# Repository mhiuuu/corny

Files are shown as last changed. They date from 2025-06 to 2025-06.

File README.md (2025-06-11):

# Corny Split Keyboard

My first custom split keyboard that takes inspiration from the [Corne keyboard](https://www.boardsource.xyz/products/Corne).

---

## Motivation

I’m pretty much a geek who always finds ways to create things tailored specifically for myself. I've been using Arch Linux (BTW), Hyprland (BTW), and Neovim (BTW) for over a year now, and most of my workflow depends heavily on the keyboard.

Over time, I’ve tried 60%, 75%, and 100% mechanical keyboards. They’re all nice, but I struggled to find space on my desk for schoolwork, and placing the keyboard on my laptop caused the battery to heat up. Then one day, I stumbled upon [this video](https://youtu.be/7UXsD7nSfDY?si=9aiY0pJiT80jEVwv), which sparked the idea—and here it is: my first-ever custom-built split keyboard. All the design work was done in less than 5 days.

---

## Build

This keyboard was created using [Ergogen](https://github.com/ergogen/ergogen), with extra helpful guidance from the [Flatfootfox tutorial](https://flatfootfox.com) and HunterCook—a genius and my friend on Discord.

The design is entirely customized for my hand movements and habits. It may not suit your typing style (or even mine, as this is my first attempt). All routing was done manually and can be found in the `ergogen/results/pcbs/` directory, not in `ergogen/output/pcbs`, which contains files auto-generated by Ergogen.

---

### 1. Layout

The layout was fully created inside [Ergogen](https://ergogen.ceoloide.com).

Here’s my initial design of _Corny_, drawn in Excalidraw:
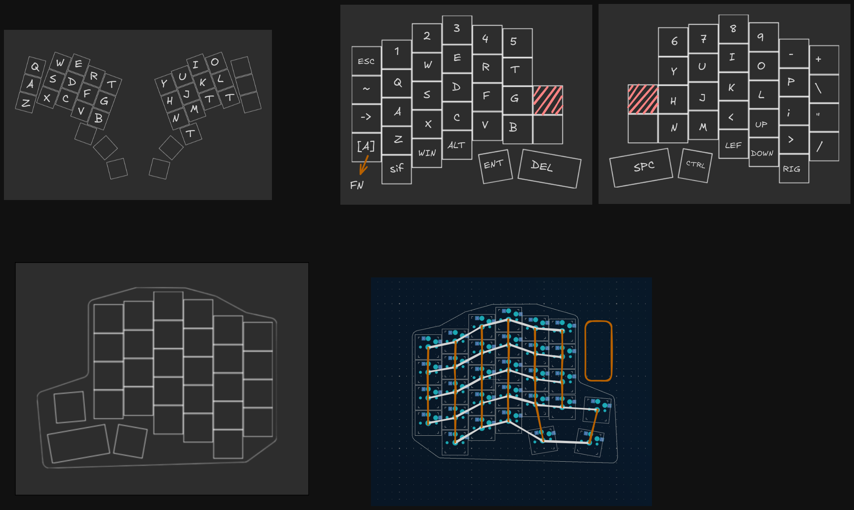
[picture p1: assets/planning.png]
Excalidraw


It was draw in the first day with some adjustments. However, while working on the board I realized that I forgot the `{}` and the `FN` key so I have to make some changes

1. Adding one more thumb key to each side (It was 2 but I have enough place for all the key I need now)
2. Changing the `CAPSLOCK` to `FN` cuz who even use it now?

---

### 2. Components

For switches, I decided to use `MX switches` instead of `Choc switches` like most others, because MX switches are much easier to find in Vietnam. In fact, I couldn’t find any retailers selling Choc switches on the major e-commerce platforms here. My switch of choice is the [Akko Rosewood](https://en.akkogear.com/product/akko-rosewood-switch/).

> Choc switch (low profile): 17×18mm

> MX switch (The type of switch on normal mechanical keyboard): 19×19mm

For the MCU, I used the [nice!nano v2](https://typeractive.xyz/products/nice-nano?variant=42225114546407) for wireless functionality despite of the fact that you can see, yep obviously the MCU in the PCBS are `nice!nano_v1` but I could only find the version 2. However, you can use almost any available MCU, such as the [Pro Micro](https://hshop.vn/arduino-pro-micro) or even a [Raspberry Pi Zero](https://www.raspberrypi.com/products/raspberry-pi-zero/).

---

### 3. PCBs

The PCBs were auto-generated by [Ergogen](https://ergogen.ceoloide.com) in `.kicad_pcb` format, which you can open in [KiCad](https://www.kicad.org/). Be sure to connect all routes manually, and aim for an `unrouted` count of zero—otherwise, you'll have unconnected components (oops!).

I had a hard time with the PCBs when I was connecting everything and remembered that _damn this should not be here_ so make sure connecting all the important components first (hardest part) before working with the keys

The finished PCBs are located in `./PCBs/` not in `./ergogen/output/pcbs/`, they are auto generated by ergogen

Here are the final PCB designs:

| Left Plate | Right Plate |
| --- | --- |
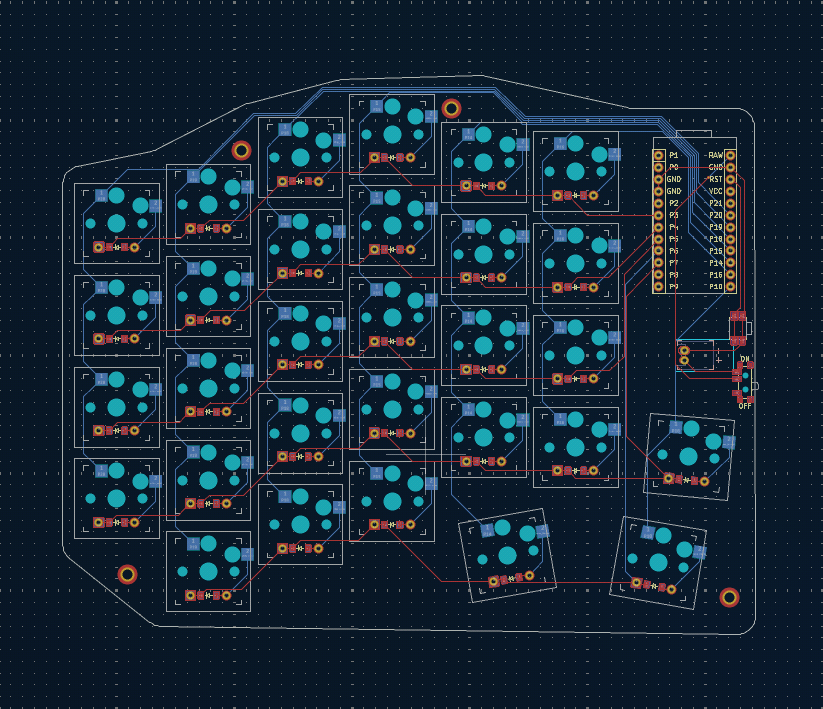
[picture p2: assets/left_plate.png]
let_plate
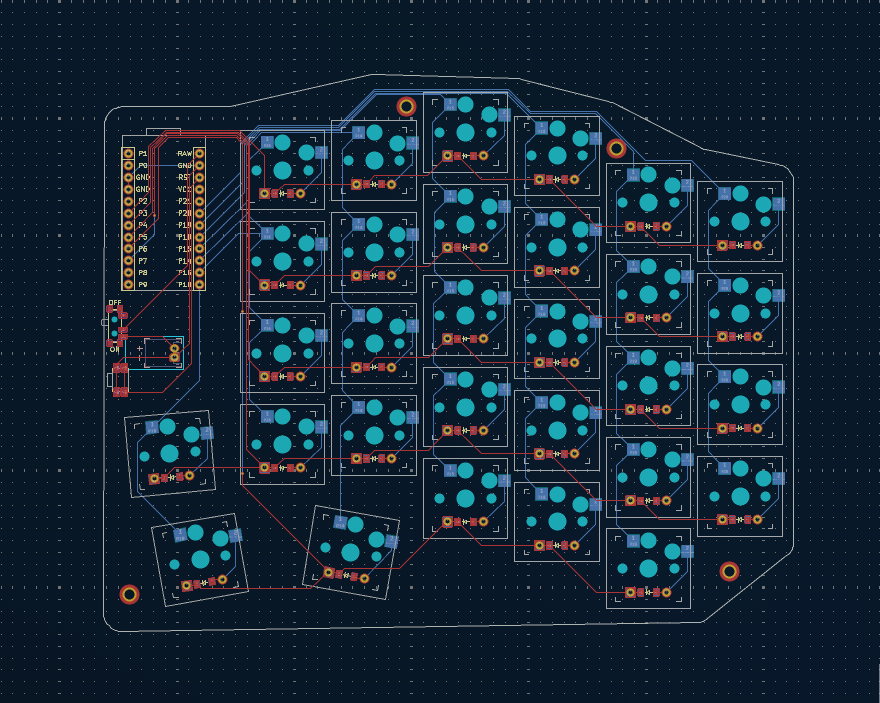
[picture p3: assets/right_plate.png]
|  |  |

---

### 4. Cases

## Version 1:

Design the case inside ergogen is possible. However, it was a pain in the ass so I made a dirty (or genius?) move by making half of the case in ergogen, the eport it in `jscad` convert to `stl` using the `@jscad/cli@1` package and then put it inside [OnShape](https://cad.onshape.com) then delete the wrong part

Here is the image of the final `stl` file

| Left case | Right case |
| --- | --- |
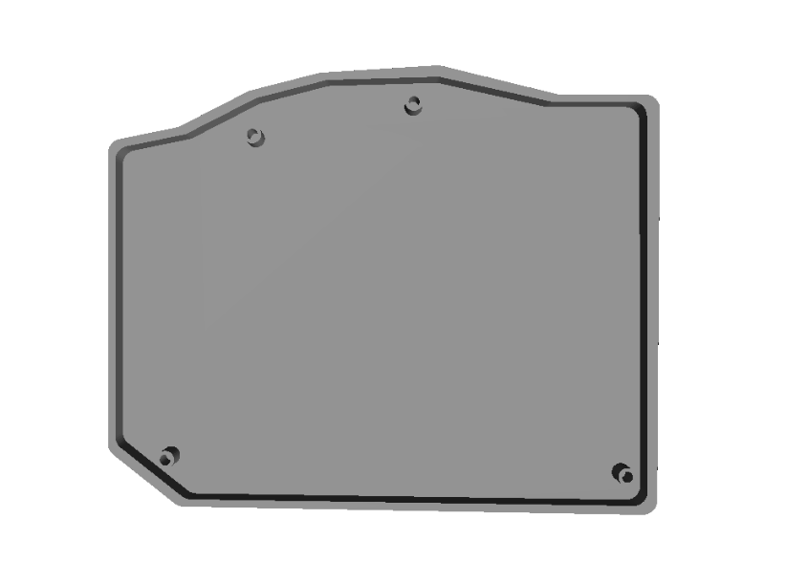
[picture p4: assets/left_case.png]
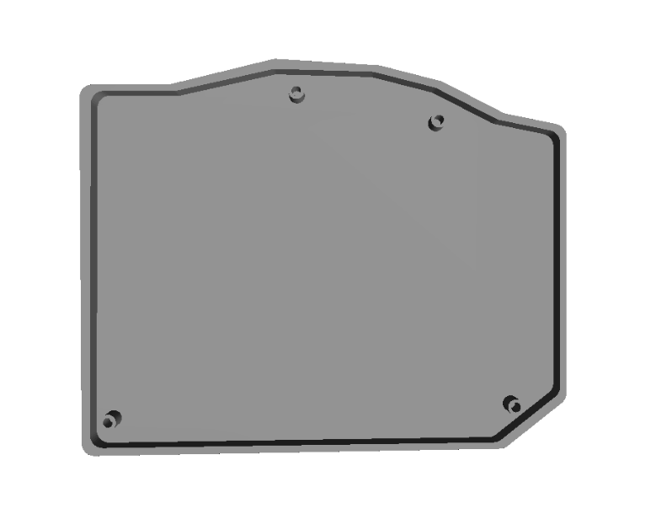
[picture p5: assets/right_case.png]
|  |  |

P/s: Im praying that the mounting hole will fit

## Version 2:

The case was denied because it was just a basic outline which you can literally create anywhere using a case genereator. So I decided to sit back and start working with [OnShaped](https://cad.onshape.com) to design a new case.

First, I imported the `.dxf` files from the `./ergogen/output/outline` and lay it on to the sketch so that I can have a brief view of what the outlines are. (Disclaimer: the outline is 10 times the actual size so after all you have to scale it down) Then I extrude the parts I need to create a simple case as the `version_1`.

Then I have to create the nut for M2 screws but I had had a bad time with creating custom nut and screw so I decided to use the public version of a M2 nut and extrude it so that it has a little margin I need to stand the PCBs.

Next step is the worst step you can imagine, making the top plate!!! I had to redo the first step of making the case (creating a plate without the walls) the align it so that the keys hole and the plate aligned perfectly. Then I had to extrude each key individually!!!!! That is over 30 keys and yes it took a whooping amount of timeto do it. Also remember to cut the hole for the MCU to (you don't want to cut it manually when you got the 3D printed case tho)

Penultimate is the piercing hole for the velcro strap. This create 2 holes so that you can use the velcro strap to strap the keyboard around your leg when you are on a plane/train or just simply don't have the space for you keyboard.
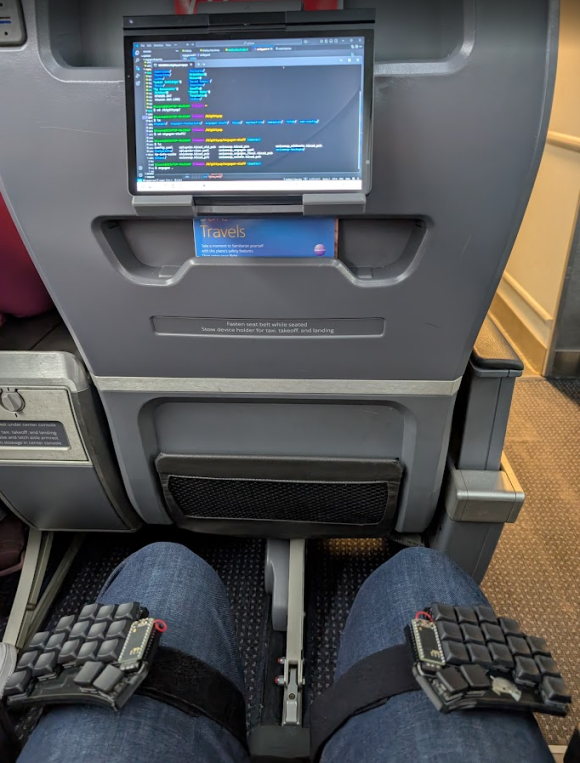
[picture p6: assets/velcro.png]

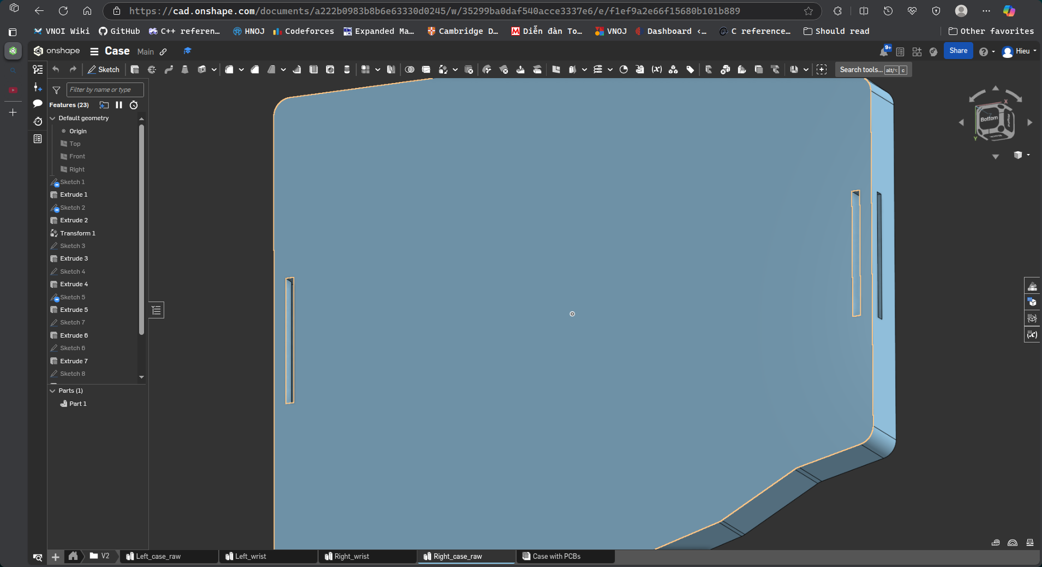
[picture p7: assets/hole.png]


Final parts are the detachable wrist rest using magnet. I use two 6mmx1.5mm magnet mounted to the case so that you can attach and remove the wrist rest with ease.
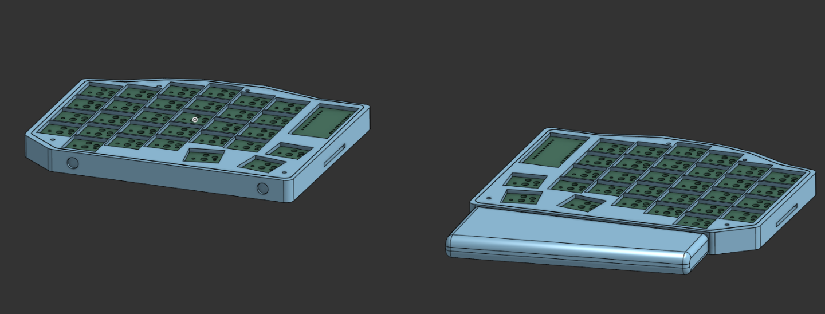
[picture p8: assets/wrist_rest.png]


---

### 5. The software

I haven't had fund to get the parts yet but there is a tool called [zmk](/zmk-corny-config/) - I will keep the repo private for now since I am just doing it blindly without the physical parts

---

### 6. BOM

AYou can check the BOM in [here](/Corny_BOM.csv). As you can see, the prices look a bit messy—that's the best I could do when converting between VND and USD (inflation is killing me). Only Shopee Vietnam, a Vietnamese e-commerce platform, lists exact prices in VND, which I then converted to USD. All the other retailers charge in USD. Even more frustrating, Typeractive actually charges more in VND than in USD!

#### Electronics

| No. | Parts | Unit cost (USD) | Unit cost (VND) | Quantity | Retailer | Shipping + Tax (USD) | Shipping + Tax (VND) | Total cost (USD) | Total cost (VND) | Source | Note |
| --- | --- | --- | --- | --- | --- | --- | --- | --- | --- | --- | ---- |
| 1 | Nice!nano MCU | 25.41 | 662,000 | 2 | Typeractive | Free | Free | 50.82 | 1324000 | https://typeractive.xyz/products/nice-nano?variant=42225114546407 | |
| 2 | Power Switch | 1.54 | 40,000 | 1 | Typeractive | Free | Free | 1.54 | 40000 | https://typeractive.xyz/products/power-switch?variant=45597854171367 | |
| 3 | Diodes | 0.77 | 20,000 | 6 | Typeractive | Free | Free | 5.62 | 120000 | https://typeractive.xyz/products/smd-diodes?variant=45597514858727 | |
| 4 | Reset button | 1.54 | 40,000 | 1 | Typeractive | Free | Free | 1.54 | 40000 | https://typeractive.xyz/products/reset-button?variant=45597784932583 | |
| 5 | Battery jack | 1.04 | 27,000 | 1 | Typeractive | Free | Free | 1.04 | 27000 | https://typeractive.xyz/products/battery-jack?_pos=2&_psq=bat&_ss=e&_v=1.0 | |
| 6 | Machine Sockets and Pins | 6.61 | 172,000 | 2 | Typeractive | Free | Free | 13.22 | 344000 | https://typeractive.xyz/products/machine-sockets-and-pins?variant=45741664469223 | |
| 7 | Kailh Hotswap Sockets | 1.54 | 40,000 | 6 | Typeractive | Free | Free | 9.24 | 240000 | https://typeractive.xyz/products/hotswap-sockets?_pos=1&_psq=hot&_ss=e&_v=1.0 | |
| 8 | PCBs | 10.7 | 278,960 | 2 | JLCPCB | 12.47 | 324,470 | 33.87 | 882390 | https://jlcpcb.com | |
| 9 | Battery | 1.53 | 39,820 | 2 | Shopee VN | 0.39 | 10,000 | 3.45 | 89640 | https://shopee.vn/Ehbqna-103450-Pin-s%E1%BA%A1c-lithium-polymer-lipo-3.7V-2000MAH-m%E1%BB%9Bi-i.240549284.26978776277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 | |

**Electronics Total**: **119.34 USD** / **3,107,030 VND**

#### Hardware

| No. | Parts | Unit cost (USD) | Unit cost (VND) | Quantity | Retailer  | Shipping + Tax (USD) | Shipping + Tax (VND) | Total cost (USD) | Total cost (VND) | Source | Note  |
| --- | --- | --- | --- | --- | --- | --- | --- | --- | --- | --- | ----- |
| 1 | Akko Rosewood | 0.29 | 7,499 | 60 | Shopee VN | 0.64 | 16,500 | 18.04 | 466440 | https://shopee.vn/Switch-Akko-Cream-V3-Pro-Yellow-Blue-Piano-Silent-Fairy-Linear-Penguin-Tactile-Switch-Akko-Cream-Yellow-Blue-DoDo-Gear-i.665488736.23277505182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 | |
| 2 | Keycaps | 0.38 | 9,900 | 58 | Shopee VN | 0.71 | 18,300 | 22.75 | 592500 | https://shopee.vn/-Cherry-Keycap-Blank-1u-Trong-Su%E1%BB%91t-N%C3%BAt-Keycap-L%E1%BA%BB-Trong-Su%E1%BB%91t-Cho-B%C3%A0n-Ph%C3%ADm-C%C6%A1-Switch-Tester-YMDK-Cherry-P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 | |
| 3 | Solder | 2.49 | 65,000 | 1 | Shopee VN | 0.64 | 16,500 | 3.13 | 81500 | https://shopee.vn/Thi%E1%BA%BFc-H%C3%A0n-63-37-SN63-Flux-1.8-Cu%E1%BB%99n-50G-i.27117857.29208587865 | |
| 4 | Soldering station | N/A | N/A | N/A | Owned | - | - | - | - | | Owned |
| 5 | 3D printed cases  | 13.78 | 358,556 | 1 | JLCPCB | Free | Free | 13.78 | 358,556 | https://jlcpcb.com | |
| 6 | Tenting feet | 2.45 | 63,800 | 2 | Shopee VN | 0.58 | 15,000 | 4.9 | 142600 | https://shopee.vn/Mini-Di-%C4%90%E1%BB%99ng-H%E1%BB%A3p-Kim-K%E1%BA%BDm-Laptop-%C4%90%E1%BB%A9ng-B%C3%A0n-Ph%C3%ADm-M%C3%A1y-T%C3%ADnh-Ch%C3%A2n-Gi%C3%A1-%C4%90%E1%B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 | |

**Hardware Total**: **62.6 USD** / **1,641,596 VND**

---

### 💰 TOTAL COST

-   **Electronics**: 3,107,030 VND / 119.34 USD
-   **Hardware**: 1,641,596 VND / 62.6 USD
-   **Grand Total**: **4,748,626 VND / 181.94 USD**

_Disclaimer: When you try to converting VND to USD you can see that they are about ~1 dollar away from each other. It is because you can not accurately convert the price down to every cent._

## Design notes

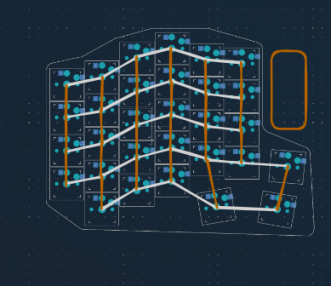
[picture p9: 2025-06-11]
assets/matrix_draft.png

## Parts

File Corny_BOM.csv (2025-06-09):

Electronics
No. | Parts | Unit cost (USD) | Unit cost (VND) | Quantity | Retailer | Shipping + Tax (USD) | Shipping + Tax (VND) | Total cost (USD) | Total cost (VND) | Source | Note
1 | Nice!nano MCU | 25.41 | 662,000 | 2 | Typeractive | Free | Free | 50.82 | 1324000 | https://typeractive.xyz/products/nice-nano?variant=42225114546407
2 | Power Switch | 1.54 | 40,000 | 1 | Typeractive | Free | Free | 1.54 | 40000 | https://typeractive.xyz/products/power-switch?variant=45597854171367
3 | Diodes | 0.77 | 20,000 | 6 | Typeractive | Free | Free | 4.62 | 120000 | https://typeractive.xyz/products/smd-diodes?variant=45597514858727
4 | Reset button | 1.54 | 40,000 | 1 | Typeractive | Free | Free | 1.54 | 40000 | https://typeractive.xyz/products/reset-button?variant=45597784932583
5 | Battery jack | 1.04 | 27,000 | 1 | Typeractive | Free | Free | 1.04 | 27000 | https://typeractive.xyz/products/battery-jack?_pos=2&_psq=bat&_ss=e&_v=1.0
6 | Machine Sockets and Pins | 6.61 | 172,000 | 2 | Typeractive | Free | Free | 13.22 | 344000 | https://typeractive.xyz/products/machine-sockets-and-pins?variant=45741664469223
7 | Kailh Hotswap Sockets (MX) | 1.54 | 40,000 | 6 | Typeractive | Free | Free | 9.24 | 240000 | https://typeractive.xyz/products/hotswap-sockets?_pos=1&_psq=hot&_ss=e&_v=1.0
8 | PCBs | 10.7 | 278,960 | 2 | JLCPCB | 12.47 | 324,470 | 33.87 | 882,390 | https://jlcpcb.com
9 | Battery | 1.53 | 39,820 | 2 | Shopee Vietnam | 0.39 | 10,000 | 3.45 | 89,640 | https://shopee.vn/Ehbqna-103450-Pin-s%E1%BA%A1c-lithium-polymer-lipo-3.7V-2000MAH-m%E1%BB%9Bi-i.240549284.26978776277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
TOTAL COST |  |  |  |  |  |  |  | 119.34 | 3107030
Hardware
No. | Parts | Unit cost | Unit cost (VND) | Quantity | Retailer | Shipping + Tax (USD) | Shipping + Tax (VND) | Total cost (USD) | Total cost (VND) | Source | Note
1 | Akko Rosewood | 0.29 | 7,499 | 60 | Shopee Vietnam | 0.64 | 16,500 | 18.04 | 466,440 | https://shopee.vn/Switch-Akko-Cream-V3-Pro-Yellow-Blue-Piano-Silent-Fairy-Linear-Penguin-Tactile-Switch-Akko-Cream-Yellow-Blue-DoDo-Gear-i.665488736.232775051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
2 | Keycaps | 0.38 | 9,900 | 58 | Shopee Vietnam | 0.71 | 18,300 | 22.75 | 592,500 | https://shopee.vn/-Cherry-Keycap-Blank-1u-Trong-Su%E1%BB%91t-N%C3%BAt-Keycap-L%E1%BA%BB-Trong-Su%E1%BB%91t-Cho-B%C3%A0n-Ph%C3%ADm-C%C6%A1-Switch-Tester-YMDK-C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
3 | Solder | 2.49 | 65,000 | 1 | Shopee Vietnam | 0.64 | 16,500 | 3.13 | 81,500 | https://shopee.vn/Thi%E1%BA%BFc-H%C3%A0n-63-37-SN63-Flux-1.8-Cu%E1%BB%99n-50G-i.27117857.29208587865
4 | Soldering station | N/A |  |  |  |  |  |  |  |  | Owned
5 | 3D Printed case | 13.78 | 358,556 | 1 | JLCPCB | Free | Free | 13.78 | 358,556 | https://jlcpcb.com | Shipping fee can be included with the PCBs
6 | Tenting feet | 2.45 | 63,800 | 2 | Shopee Vietnam | 0.58 | 15,000 | 4.9 | 142,600 | https://shopee.vn/Mini-Di-%C4%90%E1%BB%99ng-H%E1%BB%A3p-Kim-K%E1%BA%BDm-Laptop-%C4%90%E1%BB%A9ng-B%C3%A0n-Ph%C3%ADm-M%C3%A1y-T%C3%ADnh-Ch%C3%A2n-Gi%C3%A1-%C4%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
TOTAL COST |  |  |  |  |  |  |  | 62.6 | 1,641,596
TOTAL COST
 |  | VND | USD
1 | Electronics | 3,107,030 | 119.34
2 | Hardware | 1,641,596 | 62.6
 | TOTAL | 4,748,626 | 181.94

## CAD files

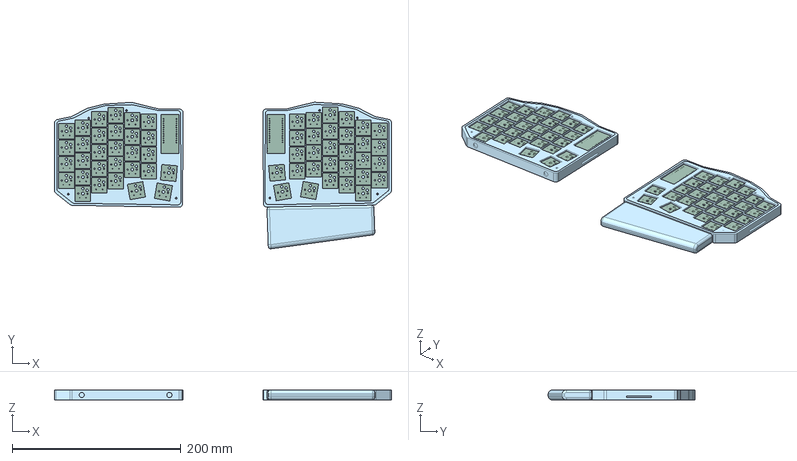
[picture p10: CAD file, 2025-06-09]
3D/V2/Case with PCBs.step
399.6 x 173.9 x 12.0 mm
M2 hex nut x 8
left_finished_PCB
right_finished_PCB

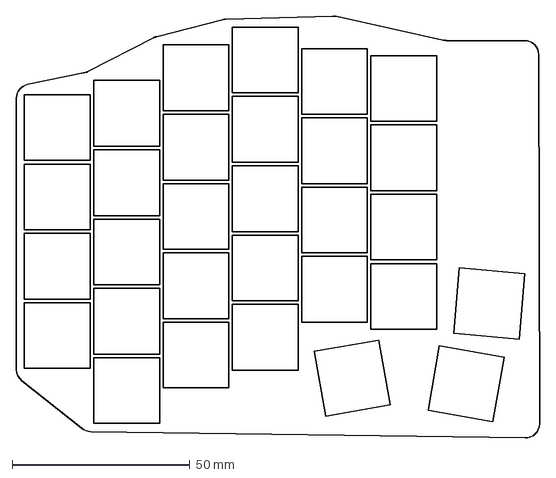
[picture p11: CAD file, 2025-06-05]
ergogen/output/outlines/combo.dxf
147.2 x 118.7 mm

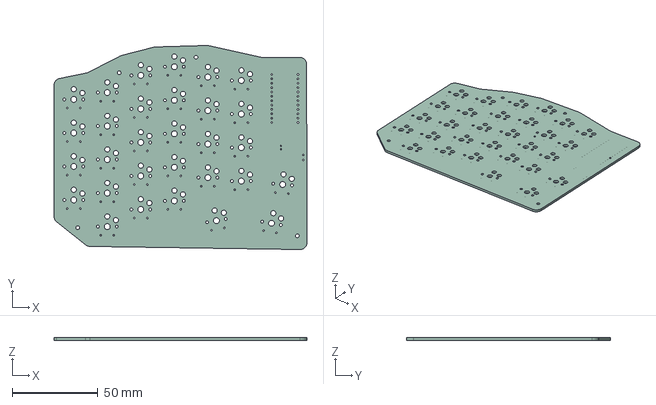
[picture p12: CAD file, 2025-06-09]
PCBs/left_finished.step
147.2 x 118.7 x 1.51 mm

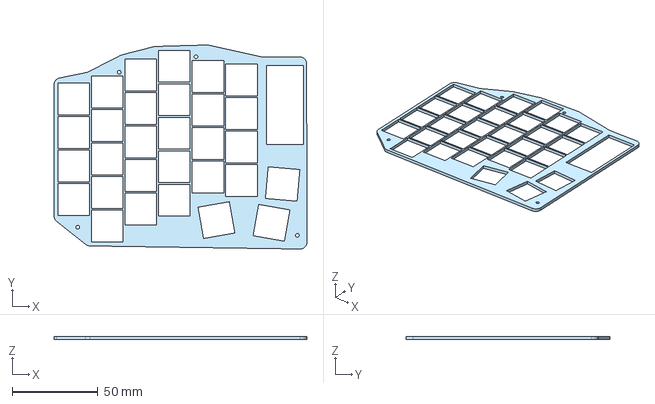
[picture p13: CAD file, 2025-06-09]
3D/V2/Top plate.step
147.2 x 118.7 x 2.00 mm

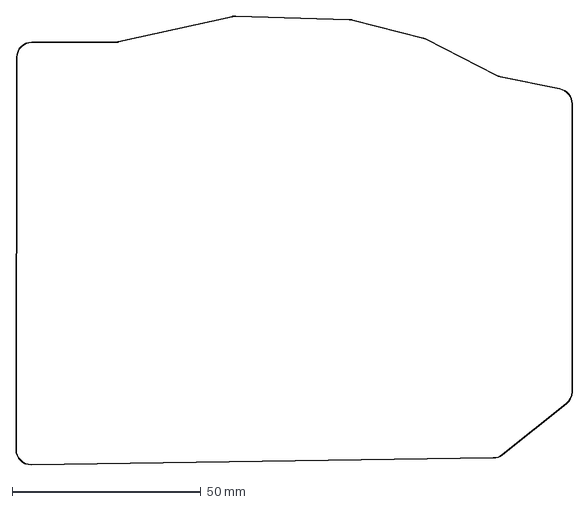
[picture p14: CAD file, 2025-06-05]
ergogen/output/outlines/board_right.dxf
147.2 x 118.7 mm

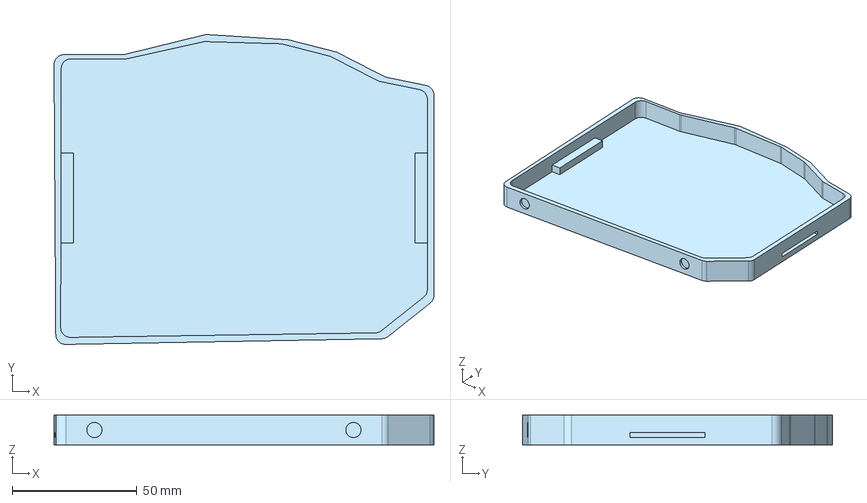
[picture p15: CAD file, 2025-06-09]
3D/V2/Right_case_raw.step
152.5 x 124.4 x 12.0 mm

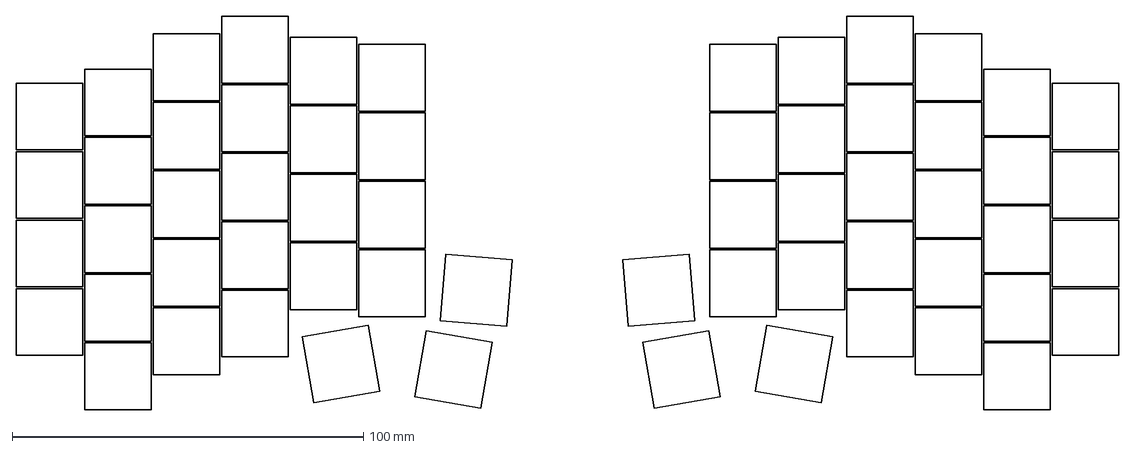
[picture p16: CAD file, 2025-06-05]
ergogen/output/outlines/raw.dxf
314.0 x 112.0 mm

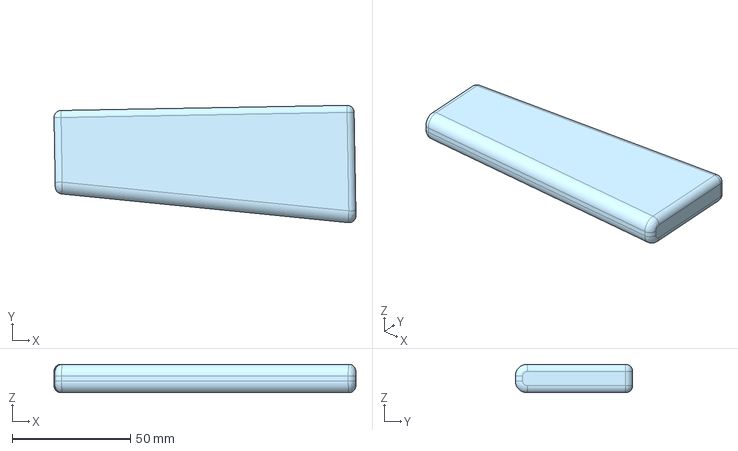
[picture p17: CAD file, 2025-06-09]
3D/V2/Right_wrist.step
127.7 x 49.6 x 12.0 mm

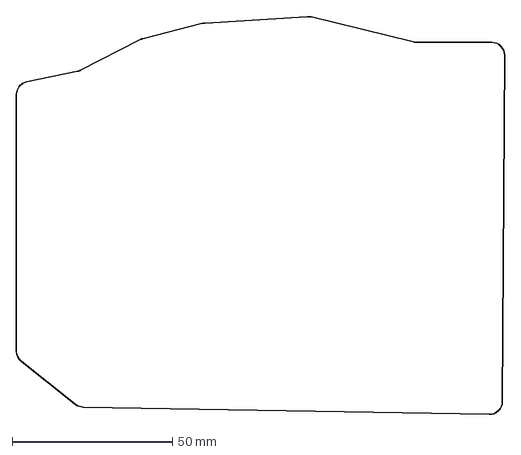
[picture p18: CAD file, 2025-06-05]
ergogen/output/outlines/xl_board_left.dxf
152.5 x 124.4 mm

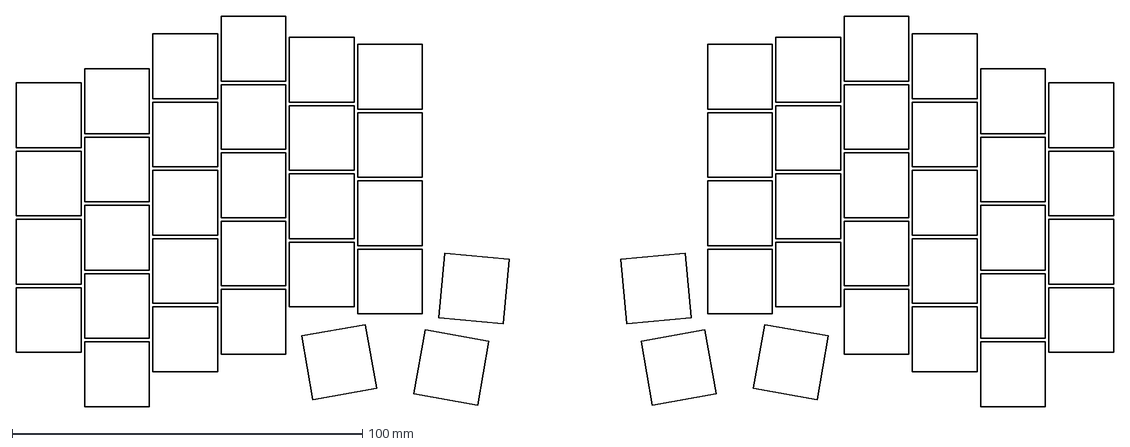
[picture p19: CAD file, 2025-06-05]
ergogen/output/outlines/keys.dxf
313.5 x 111.5 mm

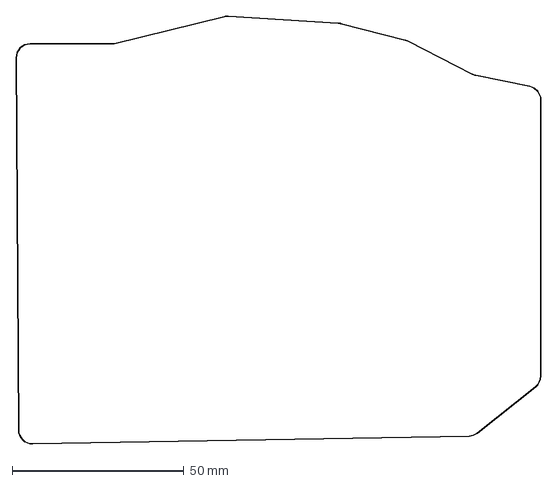
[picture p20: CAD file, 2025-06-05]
ergogen/output/outlines/xl_board_right.dxf
152.5 x 124.4 mm

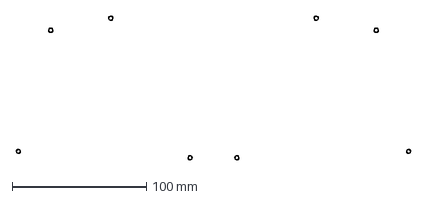
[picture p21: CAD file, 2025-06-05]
ergogen/output/outlines/mounting.dxf
293.4 x 106.9 mm

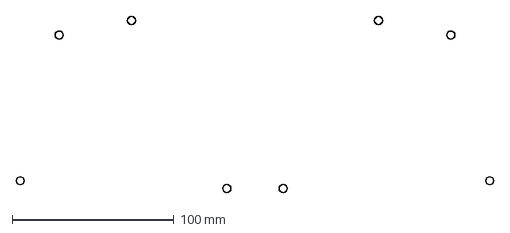
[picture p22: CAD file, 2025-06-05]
ergogen/output/outlines/standoff.dxf
295.4 x 108.9 mm

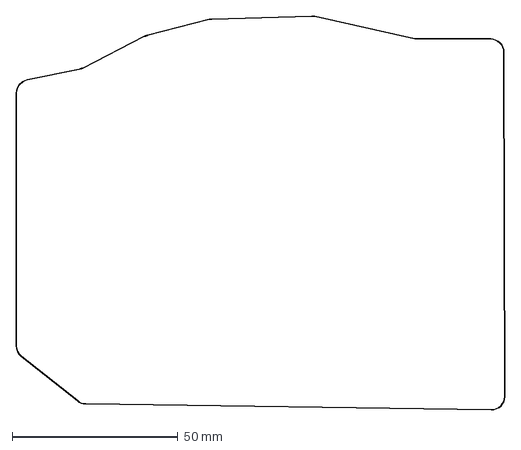
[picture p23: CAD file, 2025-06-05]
ergogen/output/outlines/board_left.dxf
147.2 x 118.7 mm

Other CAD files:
PCBs/right_finished.step
3D/V2/Left_wrist.step
3D/V2/Left_case_raw.step
3D/V1/left_case.step
3D/V1/left_case.stl
3D/V1/right_case.step
3D/V1/right_case.stl

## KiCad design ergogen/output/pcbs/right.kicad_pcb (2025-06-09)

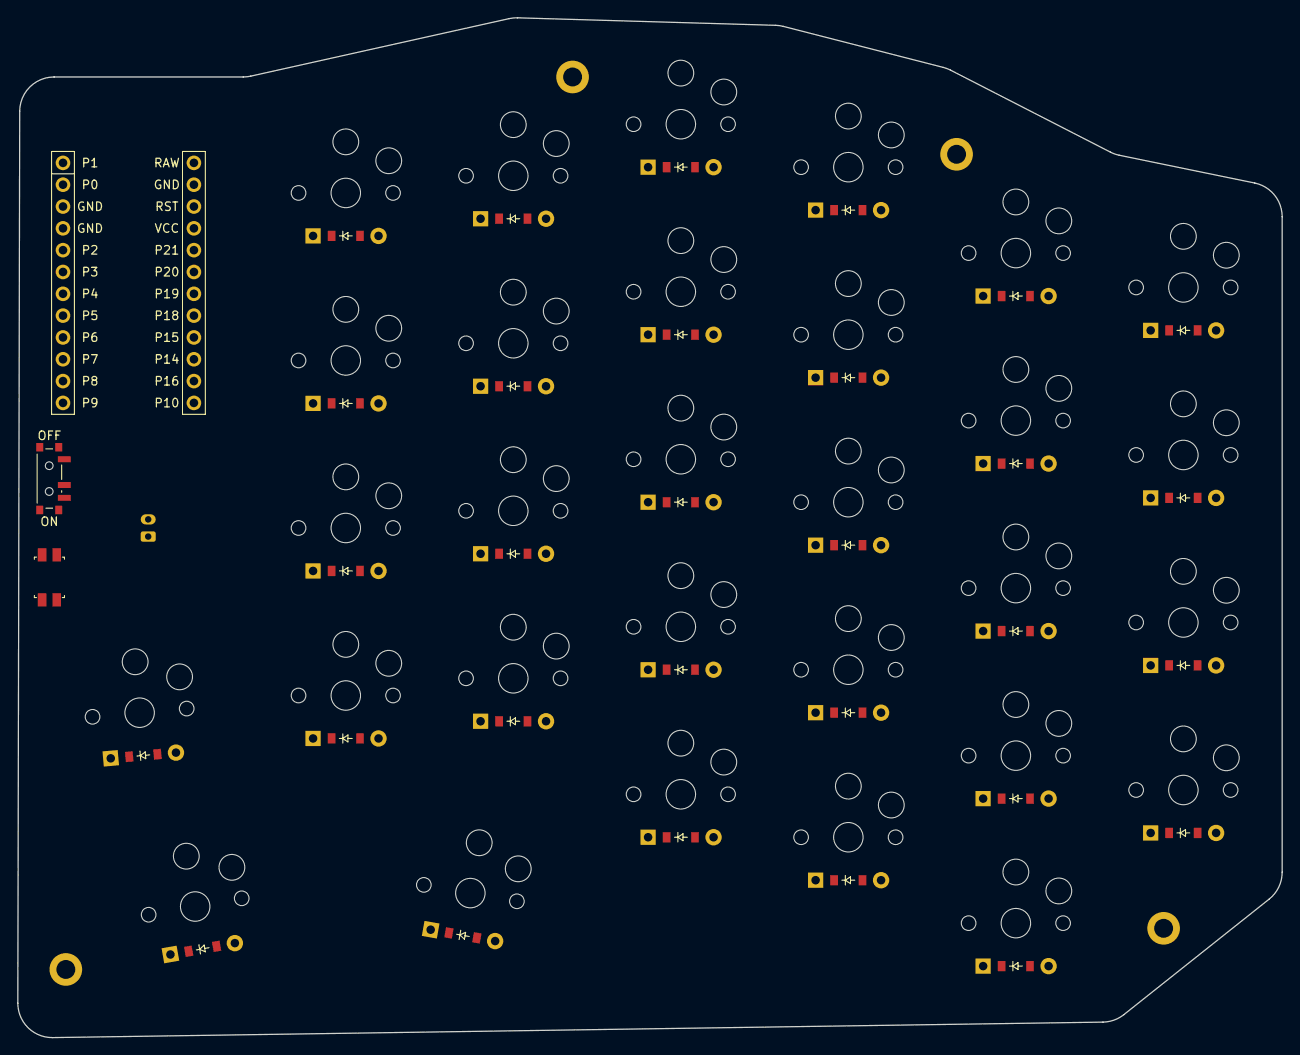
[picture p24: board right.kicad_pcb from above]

Board: 2 copper layers, 147.2 x 118.7 mm, 68 parts (1 on the bottom side), 46 nets, no tracks yet.

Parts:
D1, D2, D3, D4, D5, D6, D7, D8, D9, D10, D11, D12, D13, D14, D15, D16, D17, D18, D19, D20, D21, D22, D23, D24, D25, D26, D27, D28, D29, D30: ComboDiode
H1, H2, H3, H4: mounting_hole_plated
JST1: battery_connector_jst_ph_2
MCU1: mcu_nice_nano
PWR1: power_switch_smd_side
RST1: reset_switch_smd_side
S1, S2, S3, S4, S5, S6, S7, S8, S9, S10, S11, S12, S13, S14, S15, S16, S17, S18, S19, S20, S21, S22, S23, S24, S25, S26, S27, S28, S29, S30: PG1350

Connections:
BAT_P: JST1.2, PWR1.3
GND: JST1.1, MCU1.2, MCU1.21, MCU1.22, RST1.1, RST1.3
P3: D4.1, D9.1, D14.1, D19.1, D23.1, D27.1, MCU1.19
P4: D3.1, D8.1, D13.1, D18.1, D22.1, D26.1, MCU1.18
P5: D2.1, D7.1, D12.1, D17.1, D21.1, D25.1, MCU1.17
P6: D5.1, D10.1, D15.1, D28.1, D29.1, MCU1.16
P7: D1.1, D6.1, D11.1, D16.1, D20.1, D24.1, D30.1, MCU1.15
P10: MCU1.12, S29.1, S30.1
P14: MCU1.10, S20.1, S21.1, S22.1, S23.1, S28.1
P15: MCU1.9, S15.1, S16.1, S17.1, S18.1, S19.1
P16: MCU1.11, S24.1, S25.1, S26.1, S27.1
P18: MCU1.8, S10.1, S11.1, S12.1, S13.1, S14.1
P19: MCU1.7, S5.1, S6.1, S7.1, S8.1, S9.1
P20: MCU1.6, S1.1, S2.1, S3.1, S4.1
RAW: MCU1.1, PWR1.2
RST: MCU1.3, RST1.2, RST1.4
mirror_index_row0: D20.2, S20.2
mirror_index_row1: D21.2, S21.2
mirror_index_row2: D22.2, S22.2
mirror_index_row3: D23.2, S23.2
mirror_inner_row0: D24.2, S24.2
mirror_inner_row1: D25.2, S25.2
mirror_inner_row2: D26.2, S26.2
mirror_inner_row3: D27.2, S27.2
mirror_long_thumbs: D29.2, S29.2
mirror_middle_arrow: D15.2, S15.2
mirror_middle_row0: D16.2, S16.2
mirror_middle_row1: D17.2, S17.2
mirror_middle_row2: D18.2, S18.2
mirror_middle_row3: D19.2, S19.2
mirror_near_thumbs: D28.2, S28.2
mirror_one_bracket: D30.2, S30.2
mirror_outer_row0: D1.2, S1.2
mirror_outer_row1: D2.2, S2.2
mirror_outer_row2: D3.2, S3.2
mirror_outer_row3: D4.2, S4.2
mirror_pinky_arrow: D5.2, S5.2
mirror_pinky_row0: D6.2, S6.2
mirror_pinky_row1: D7.2, S7.2
mirror_pinky_row2: D8.2, S8.2
mirror_pinky_row3: D9.2, S9.2
mirror_ring_arrow: D10.2, S10.2
mirror_ring_row0: D11.2, S11.2
mirror_ring_row1: D12.2, S12.2
mirror_ring_row2: D13.2, S13.2
mirror_ring_row3: D14.2, S14.2

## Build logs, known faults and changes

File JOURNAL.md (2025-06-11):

# Journal

This is the journal in the making of Corny. Although I didn't write this daily during the making process, I was able to recall everything using the discussion on [Absolem Discord](https://discord.gg/mCHnwwtC) and with my friend `Huntercook`.

### 28/05/2025: 1 hour spent

I went by this [video](https://youtu.be/7UXsD7nSfDY?si=z_oIVIhKWSw-gox2) on [YouTube](https://youtube.com) about how to make your own keyboard. Kinda suprised how cool and personalized it was, I decided to use it for my [Hack club High way project](https://highway.hackclub.com/). As a Linux nerd and love how you can DIY everything for your own, I dived into the world of keyboards.

It was the first day so I just checked over some resources for the project. Highly recommended you take a look at the link `Christian Selig` put under his video as it helped me a lot the days after:

1. Parts list: https://christianselig.com/2024/07/caldera-keyboard/
2. The files required to create the keyboard: https://github.com/christianselig/caldera-keyboard
3. Flatfootfox tutorial (Highly recommended, everything in here was followed along this tutorial): https://flatfootfox.com/ergogen-introduction/

Furthermore, I also watched this [video](https://www.youtube.com/watch?v=7LyziNdFlew) to understand the simple concept of a keyboard: How the keyboard matrix works, how you can use diodes to predict the signal, how you can use ergogen to get the basic plate outline, ... etc

---

### 29/05/2025: 1 hour spent

First, I followed the `Flatfootfox` tutorial to understad and create a simple board as the `Ergogen` docs is very poor written.
However, I skipped the most important part `Unit` because I didn't really understand it that much. Also quite struggle with the whole `points` thing so I decided to use the default config by `Ergogen`

| Raw | Keys |
| --- | --- |
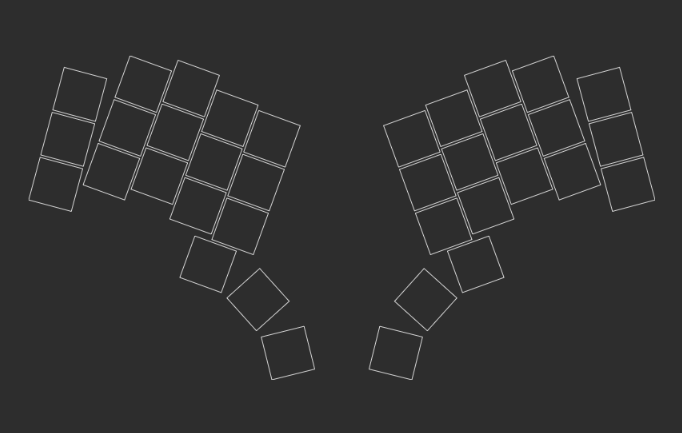
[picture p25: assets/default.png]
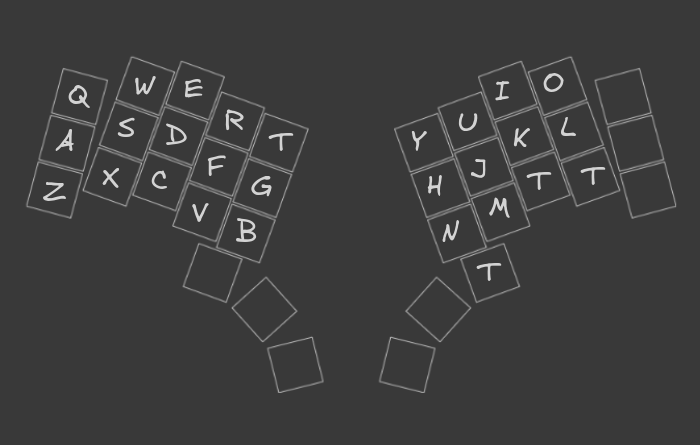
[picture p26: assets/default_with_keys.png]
|  |  |

But as we can see, there are only 3 rows of keys which mean I would not have the number row which means this config isn't really suit my style of typing so I had to create a new one but the tweaking process gave me a basic understand of how `Erogen` setup key, rows and colums work

---

### 29/05/2025: 3 hours spent

I spent the whole afternoon and evening working on this to create the proper layout of the keyboard and came up with the second version of the layout this has 4 rows (for the number row)
and I also added another column for the functional keys such as `TAB`, `Shift`, ...

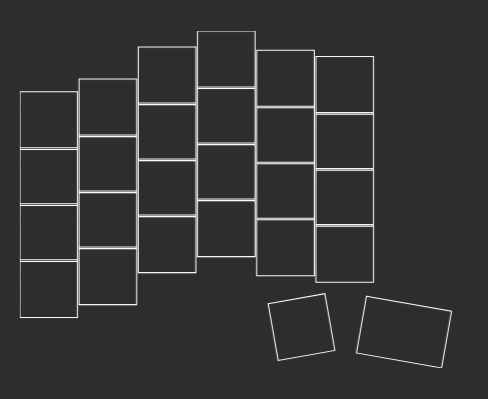
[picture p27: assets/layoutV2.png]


However I still can not find space for a lot of other keys like `FN` - crucial because I only have the number row, `Enter`, `Alt`. Moreover, some punctuation keys are also missing (especialy the curly braces) and there are no space for the arrow keys.

I was left with 2 options:

1. Add more keys
2. Create another layer of keys (Which has to be done later using zmk-config)

But obviously, this keyboard was made for me to feel comfortable with, not with style and creating another layer of keys in software means I would have to spent a lot more time learning the new keyboard which has extra learning curves and also make it difficult for me if I have to use a normal one. So we go with the first option - add more keys

This was really a pain in the ass because it took me a while to figure out where to put the new keys. But I see that there are plenty of space under the _pinky, ring and middle_ finger columns so I decided to put 3 more keys under there (which works perfectly for the arrow keys!)

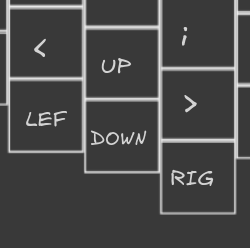
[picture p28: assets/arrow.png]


This 3 keys allowed me to have a much cleaner board with only 3 keys still being abandoned `FN` and the 2 curly braces which were solved by adding 2 more keys each next to the inner row before I decided to remove the `CAPSLOCK` to make space for the `FN` - who use `CAPSLOCK` btw. The upper key of the 2 keys I just added was also removed because the board looked nice now

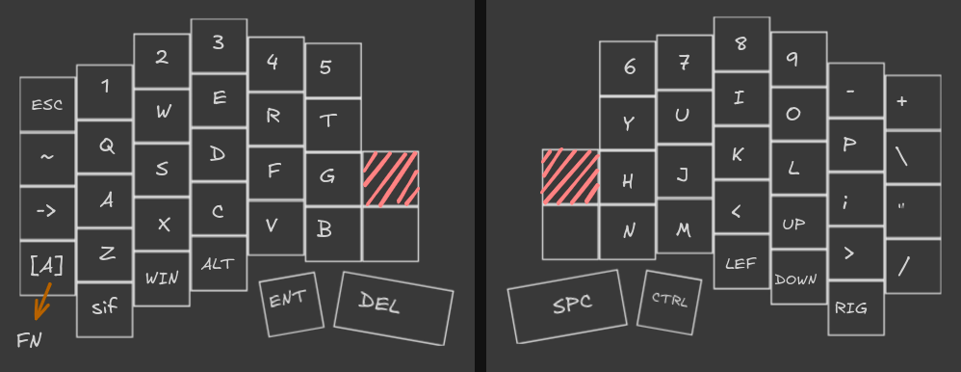
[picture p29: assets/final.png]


P/s: At the time I also tried to use some **splay** but gave the idea up cuz the board was kinda big

---

### 30/05/2025: 4 hours spent

The layout was done and now come to the hardest part in my opinion. Adding the electronics. At first all of the layout was finished inside `https://ergogen.cache.works`. However, this generator is kinda suck because you can not add your external footprints to the config. So I moved to `https://ergogen.ceoloide.com` which allows you to use your own footprints or using the external `ceoloide/...` footprints - which is much better (in my opinion).

> Despite of the assist by `Ergogen`, everytime I wanted to modify anything, I would have to change the config -> Install the `.kicad_pcb` file -> open it inside **KiCAD** again and again.

It was very time consuming and boring task.

I started with defining the matrix for the keyboard (You have to add the `MCU` of your keyboard and check the pins before specify which key goes to pin no ...). While working on this I also figured that you have to create the layout for you `MCU` also

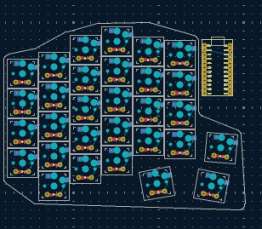
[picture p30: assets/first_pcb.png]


So what I added while doing this:

1. MCU - nice!nano
2. The power switch
3. The reset switch
4. The battery switch
5. Headphone jack to connect 2 sides

And yes you didn't hear it wrong. Doing all of this took me 4 hours of modifying the config + installing the file + taking a look if everything is fine + starting to trace some of the important components to make sure I can route them perfectly. It did drive me crazy at some point

---

### 01/06/2025: 1 hour spent

I asked people on Discord to help me check the connection and got some really good advice.

 - yes I almost burnt my keyboard alive just by wanting to connect them using the headphone jack

So I removed the `battery switch` and the `headphone jack` in order to protect the board.
After that I spent some time start connecting everything together and faced some really big problem with my design like: not reserving enough space for the other parts and traces.

Took me a while going back and forth between the config and the actual PCBs but I finished wiring for the first time ever. It was a total mess because I didn't know about the thru hole stuff

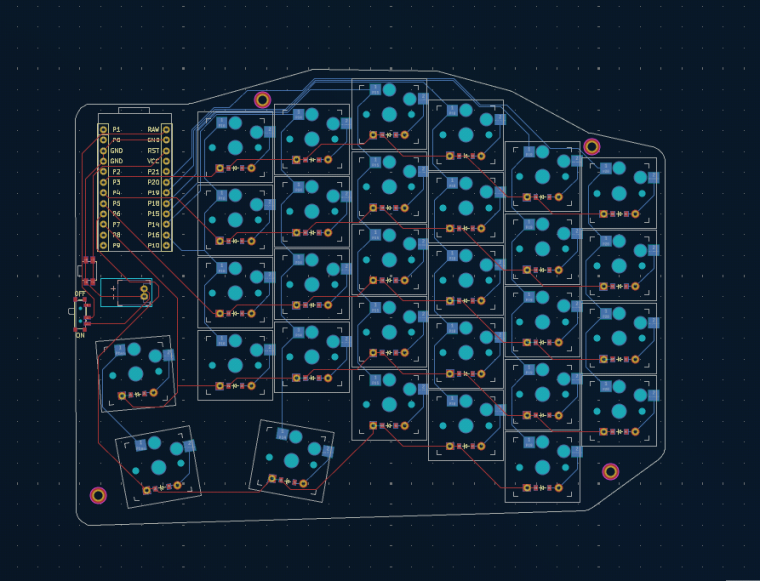
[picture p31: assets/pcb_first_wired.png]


The left side had the same appearance but it was a great start when I had some basic idea behind the concept

---

### 02/06/2025: 2 hours spent

I started redo everything on the PCBs and had a pretty neat appearance now.
I added some padding to the keyboard outline so my traces have more spacing.

But after that I realized I made the dumbest mistake a human ever could: In the config file, instead of matching the thumb keys with `P10` pin, I left them as `Pten` at the lastest refractor without fixing which means I have to redo everything again =(((. The power switch was also kinda off when placed on the outside of the boar,d so I had to move it back a bit (I just do it inside `KiCAD` without edit the config lol)

> Disclaimer: I did fix the config later



But after that everything was really nice and I finished the right plate beautifully

---

### 04/06/2025: 2 hours spent

Making the case inside was an absolute pain. I cannot do it at all, even after following the tutorial
I tried my best tweaking, figuring things out but this is the best I could get.

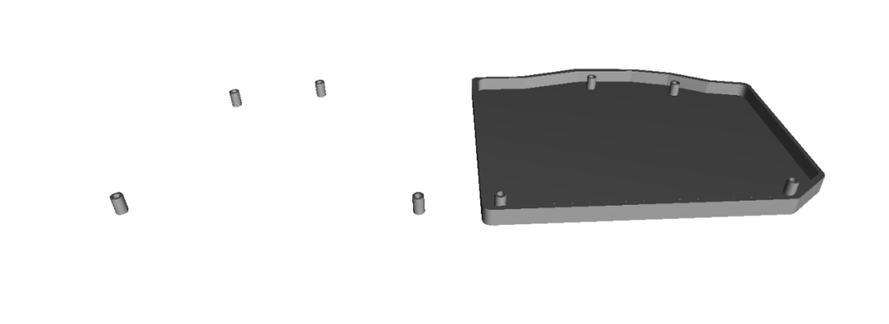
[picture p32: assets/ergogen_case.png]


So I decided to convert it from `.jscad` to `.stl` then import it inside OnShape and flip the board around, delete the unused parts the make the other case.

After that I imported everything into `JLCPCB` to get the bills.
I also started finding the suitable parts and converting them between VND and USD to make the BOM file

---

### 05/06/2025:

I submitted the project to hack club and am waiting for the result

---

### 06/06/205:

Acon said he needed the `.step` file so I converted the `.stl` to `.step` and added some images to the PCBs

---

### 07/06/2025: 2 hours spent 

The project is in pending because the case can be generated. So I started drawing the case myselft in OnShape.

I imported the `.DXF` outline files into OnShape making the simple case as the one I had already. But I still had to add some hex nut from other project cuz I can not make one myself but I think it suit the whole design.

I sparked an idea. My friend once sent me a picture of his keyboard that has a velcro strap to his leg



So I decided to do that same. It was a long journey of measuring and connecting points in OnShape but I created a simple version of it

---

### 08/06/2025: 2 hours spent

Fnished the leftside and started working on the right side while I found a better way to remove the hole for the velcro strap. Redo it again but this time it was much faster since I can make use of the first hole I created without having to remeasure everything again and again.
This is the result: a clean 0.3mmx0.3mm hanging bar for the strap



Next I also found that some keyboards have a wrist rest connected to them but obviously if there are 2 wrist rest pad merged with the keyboard, my velcro idea is useless since nobody want a big ass wrist rest lay on the lap.

So I started to find a way for me to have a detachable wrist rest. There are many ways for you to have something plug in and out but I think a magnet is the most usable and fashion way. So I created a simple 5x3x1.2cm pad with some rounding (I wanted it to be tilted, be I couldn't do it in Onshape)



The wrist rest doesn't really match my first idea but I think it still looks nice and great
You can stick them together or just simply use the keyboard without the wrist rest!

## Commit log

2025-06-05 docs(README): Add BOM in table format, some journals
2025-06-05 assets(left/right_plate): rename the plate to the correct side
2025-06-05 docs(README): Add case section
2025-06-05 docs(README): pcbs instruction / feat(pcbs): add finished pcbs files
    [left_finished.kicad_pcb, right_finished.kicad_pcb]
2025-06-06 file(3D): move to the root folder / feat(add): Add image to the PCBs
    [left_case.step, left_case.stl, left_finished.kicad_pcb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]
2025-06-09 file(3D): add new 3D case version / file(BOM): update BOM / doc(README): update case designing journal, BOM
    [Case with PCBs.step, Corny_BOM.csv, Left_case_raw.step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]
